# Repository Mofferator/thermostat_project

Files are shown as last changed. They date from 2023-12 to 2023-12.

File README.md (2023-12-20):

# IoT Temperature Sensor Project
My thermostat is a compulsive liar, and I started this project to prove it!

## Hardware
- The hardware for this project consists of an ESP32 which reads the temperature and humidity from a HDC1080 air sensor
- The board also features a usb to uart (cp2102) converter, enabling easy uploading of code in the development process

## Firmware
- The basic operation of the device is as follows
  - Read the temperature and humidity
  - Connect to the specified wifi network if possible
  - Serialize the environment data into json and send to webserver via HTTP request
  - disconnect from wifi
  - Enter deep sleep for a configurable number of seconds

## Server
- The webserver containerized, consisting of a python flask web server and a MySQL database.
- The webserver also has several webpages where the temperature readings from the various devices and rooms can be viewed

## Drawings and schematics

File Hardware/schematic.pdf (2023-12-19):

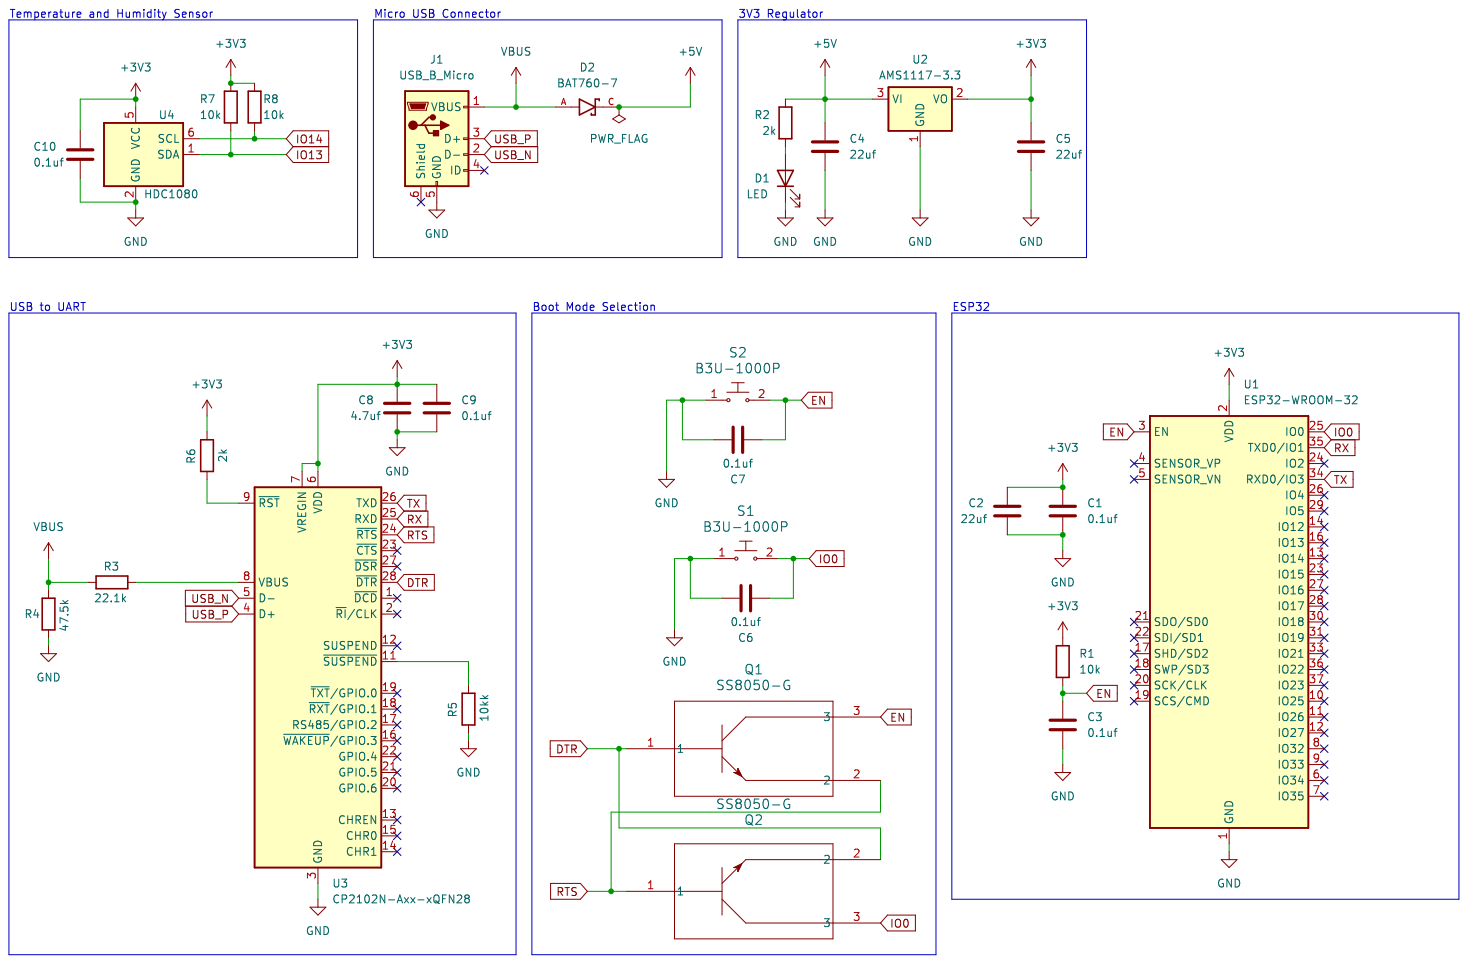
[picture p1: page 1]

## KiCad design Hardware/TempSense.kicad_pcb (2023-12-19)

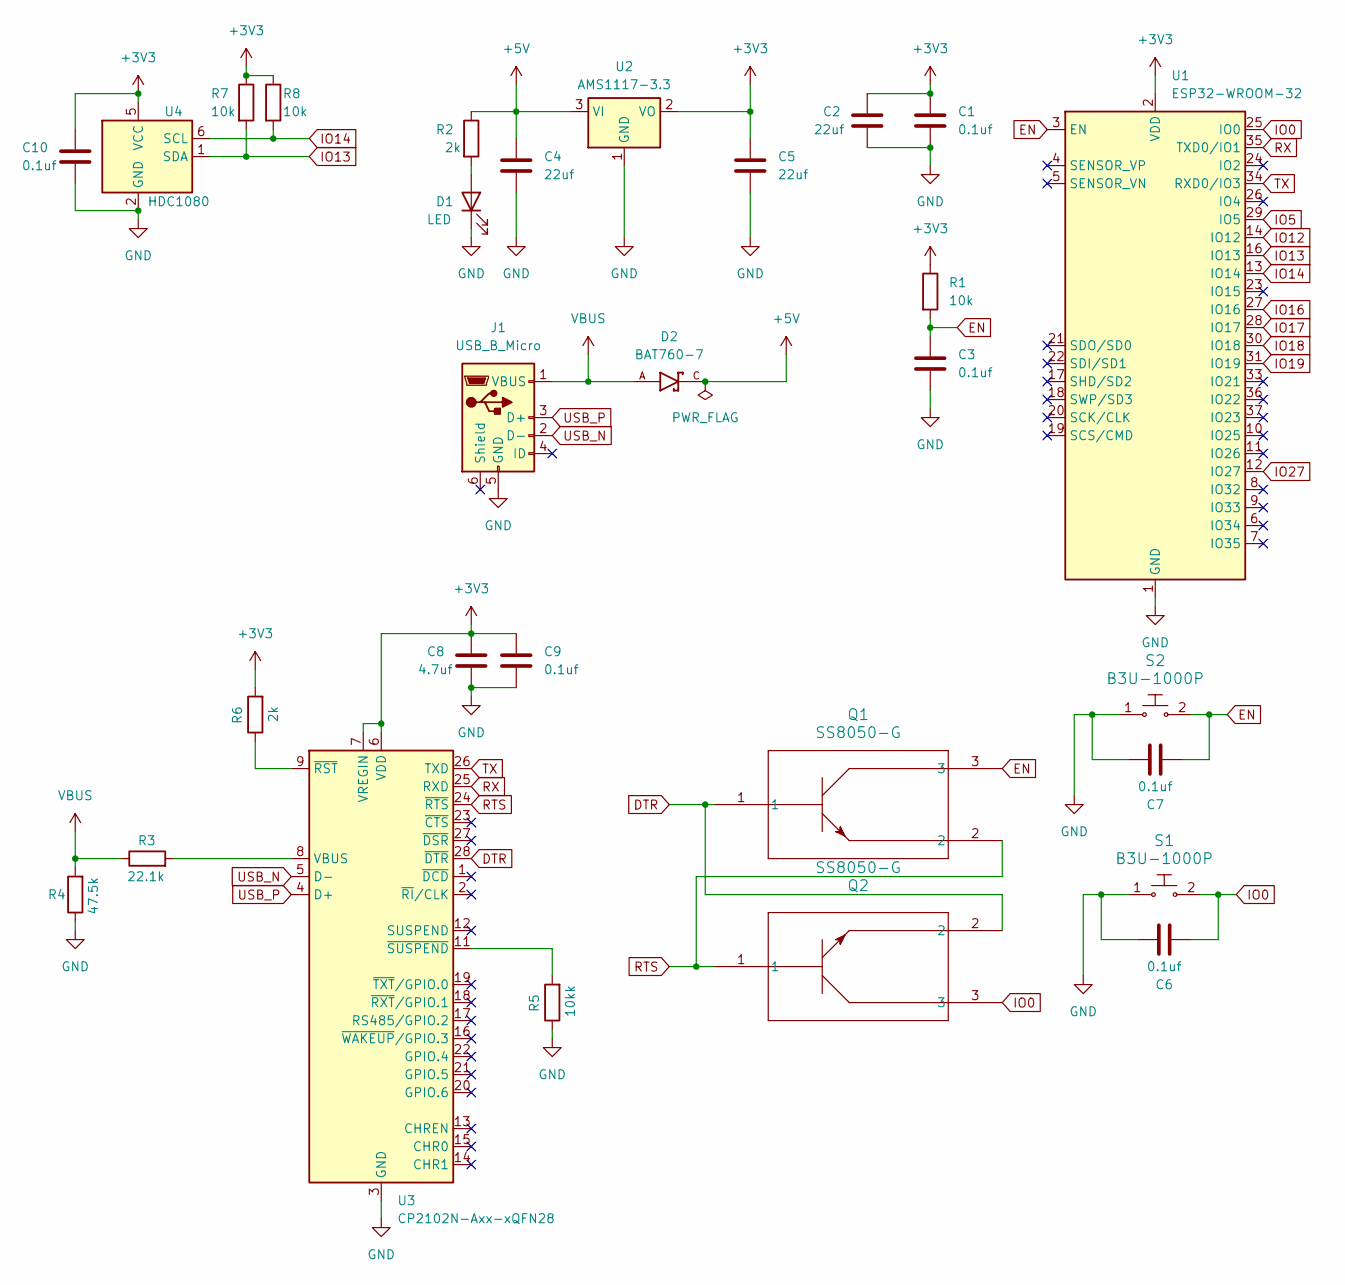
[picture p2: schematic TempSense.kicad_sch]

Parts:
C1, C3, C6, C7, C9, C10: 0.1uf; C_0402_1005Metric
C2, C4, C5: 22uf; C_0603_1608Metric
C8: 4.7uf; C_0402_1005Metric
D1: LED; LED_0603_1608Metric
D2: BAT760-7; SOD2513X120N; PARTREV 9-2
J1: USB_B_Micro; USB_Micro-B_Molex_47346-0001
Q1, Q2: SS8050-G; TRAN_SS8050-G_CIP
R1, R7, R8: 10k; R_0402_1005Metric
R2, R6: 2k; R_0402_1005Metric
R3: 22.1k; R_0402_1005Metric
R4: 47.5k; R_0402_1005Metric
R5: 10kk; R_0402_1005Metric
S1, S2: B3U-1000P; SW_Push_1P1T_XKB_TS-1187A; MPN B3U-1000P; Digi-Key_PN SW1020CT-ND
U1: ESP32-WROOM-32
U2: AMS1117-3.3; SOT-223-3_TabPin2
U3: CP2102N-Axx-xQFN28; QFN-28-1EP_5x5mm_P0.5mm_EP3.35x3.35mm
U4: HDC1080; Texas_PWSON-N6

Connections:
+3V3: C1.1, C2.1, C5.1, C8.1, C9.1, C10.1, R1.1, R6.2, R7.1, R8.1, U1.2 (VDD), U2.2 (VO), U3.6 (VDD), U3.7 (VREGIN), U4.5 (VCC)
+5V: C4.1, D2.C, R2.1, U2.3 (VI)
DTR: Q1.1, Q2.2, U3.28 (~DTR)
EN: C3.1, C7.2, Q1.3, R1.2, S2.2, U1.3 (EN)
GND: C1.2, C2.2, C3.2, C4.2, C5.2, C6.1, C7.1, C8.2, C9.2, C10.2, D1.1 (K), J1.5 (GND), R4.1, R5.1, S1.1, S2.1, U1.1 (GND), U1.15 (GND), U1.38 (GND), U1.39 (GND), U2.1 (GND), U3.3 (GND), U3.29 (GND), U4.2 (GND)
IO0: C6.2, Q2.3, S1.2, U1.25 (IO0)
IO5: U1.29 (IO5)
IO12: U1.14 (IO12)
IO13: R7.2, U1.16 (IO13), U4.1 (SDA)
IO14: R8.2, U1.13 (IO14), U4.6 (SCL)
IO16: U1.27 (IO16)
IO17: U1.28 (IO17)
IO18: U1.30 (IO18)
IO19: U1.31 (IO19)
IO27: U1.12 (IO27)
unnamed: D1.2 (A), R2.2
unnamed: R3.2, U3.8 (VBUS)
unnamed: R6.1, U3.9 (~RST)
unnamed: R5.2, U3.11 (~SUSPEND)
RTS: Q1.2, Q2.1, U3.24 (~RTS)
RX: U1.35 (TXD0/IO1), U3.25 (RXD)
TX: U1.34 (RXD0/IO3), U3.26 (TXD)
USB_N: J1.2 (D-), U3.5 (D-)
USB_P: J1.3 (D+), U3.4 (D+)
VBUS: D2.A, J1.1 (VBUS), R3.1, R4.2

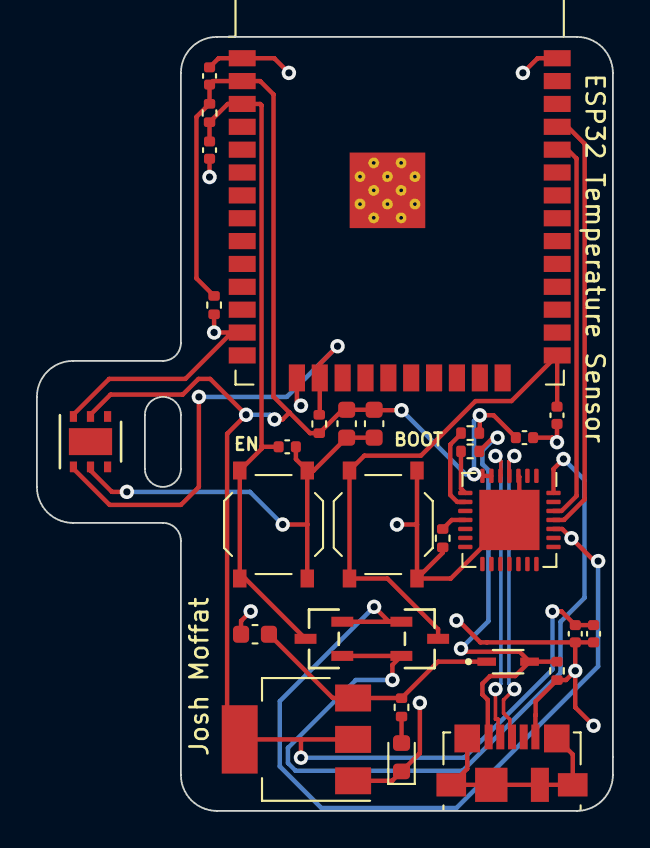
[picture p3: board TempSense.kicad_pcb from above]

Board: 2 copper layers, 32.0 x 43.0 mm, 29 parts (0 on the bottom side), 18 nets.

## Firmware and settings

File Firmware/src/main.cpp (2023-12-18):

#include <Arduino.h>
#include <iostream>
#include <secrets.h>
#include <ServerManager.h>

#define INTERVAL 60 // interval between readings in seconds
#define DEBUG false

const char* ssid = WIFI_SSID;
const char* password = WIFI_PASS;

String hostname = HOST; // hostname of web server:

void setup() {
  if (DEBUG)
    Serial.begin(115200);
  ServerManager manager(ssid, password, hostname);
  manager.Run(INTERVAL);
}

void loop() {
  // nothing here
}

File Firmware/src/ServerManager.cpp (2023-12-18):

#include <ServerManager.h>

void ServerManager::Run(int interval) {
    while(true) {
        SendData();
        esp_sleep_enable_timer_wakeup(interval * 1000000);
        Serial.println("Going to sleep...");
        esp_deep_sleep_start();
    }
}

void ServerManager::Connect() {
    WiFi.begin(mWiFiSSID.c_str(), mWiFiPassword.c_str());
    while (WiFi.status() != WL_CONNECTED) {
        delay(500);
        Serial.print(".");
    }
    Serial.print("\nConnected to ");
    Serial.println(mWiFiSSID.c_str());
    int start = millis();
    while (millis() < start + 1500){
        // wait 1.5s for wifi to connect
    }
}

void ServerManager::Disconnect() {
    WiFi.disconnect();
    Serial.printf("Disconnected from %s\n", mWiFiSSID.c_str());
}

void ServerManager::SendData() {
    auto measurement = Measurement(hdc1080, mDeviceID);
    Connect();
    configTime(gmtOffset_sec, daylightOffset_sec, ntpServer);
    measurement.RecordTime();
    mDeviceID = NegotiateDeviceID();
    measurement.SetDeviceID(mDeviceID);
    Serial.println(to_string(measurement.Serialize()).c_str());
    SendHTTP(measurement.Serialize());
    Disconnect();
}

int ServerManager::NegotiateDeviceID() {
    HTTPClient http;
    String mac = WiFi.macAddress();
    http.begin(client, "http://" + mHostName + "/new_device/" + mac + "/");
    int resp = http.GET();
    Serial.print("Response Code: ");
    Serial.println(resp);
    if (resp == 200) {
    String payload = http.getString();
    Serial.print(payload);
    auto response = nlohmann::json::parse(payload);
    if (response.contains("error")){
        String err = response["error"].get<std::string>().c_str();
        Serial.println("ERROR:");
        Serial.print(err);
        digitalWrite(ERROR_PIN, HIGH);
        return 0;
    }
    else {
        int device_id = response["device_id"].get<int>();
        
        Serial.print("Recieved new device ID: ");
        Serial.println(device_id);
        return device_id;
    }
    }
    else {
    return 0;
    }
}

void ServerManager::SendHTTP(const nlohmann::json& json) {
    const char* payload = to_string(json).c_str();
    int content_len = std::strlen(payload);

    HTTPClient http;
    http.begin(client, "http://" + mHostName + "/");
    http.addHeader("Content-Type", "application/json");
    http.addHeader("Content-Length", String(content_len));

    int resp = http.POST(payload);

    Serial.print("Response Code: ");
    Serial.println(resp);
    payload = http.getString().c_str();
    nlohmann::json response(payload);

    if (response.contains("error")) {
        Serial.print("Error: ");
        String err = response["error"].get<std::string>().c_str();
        Serial.print(err);
    } else if (response.contains("msg")) {
        String msg = response["msg"].get<std::string>().c_str();
        Serial.println(msg);
    }
}

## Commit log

2023-05-03 Added DDL for basic database to hold temperature data and device info
2023-05-03 Added sample data to initdb.sql as well as a basic route showing it
2023-05-05 Added arduino PlatformIO project
2023-05-05 Configured send_data func to read current time and temperature
2023-12-19 Added kicad files from hardware
    [TempSense.kicad_pcb, TempSense.kicad_sch]
2023-12-19 Added labels to shematic and produced pdf version
    [TempSense.kicad_sch]
